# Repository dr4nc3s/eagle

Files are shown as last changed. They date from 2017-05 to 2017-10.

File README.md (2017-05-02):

# eagle #

My own Eagle components library as well as any PCB projects/designs I choose to work on. 

## Current Project - SAML21J breakout ##

Breakout board for using the SAML21J (yep, 64-pin). Currently putting together a list of features I want on the board. Don't want to make this too expensive, but I want enough features for me to utilize the various functions of the SAML21.

<h4>Features to Include</h4>
1. Power Supply : rails for 3.3V, 5V
2. microUSB port : for power input and programming
3. 10-pin JTAG header : for programming
4. External VREF circuitry : was told that internal VREF has a fair percentage error, so will want this out
5. Peripheral IO breakouts : breakouts specifically for some of the additional functions of the pins (I2C, UART, SPI, etc)
6. Status LEDs
7. USB-UART bridge (?) : unsure if I want this

## Future Projects ##

1. ESP32 breakout board (utilize WROOM module)
2. PIC breakout board - unsure whether I want PIC18, PIC24, or PIC32 architecture
3.

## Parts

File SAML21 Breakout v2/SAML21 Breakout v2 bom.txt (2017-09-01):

Partlist exported from C:/Users/Mobile Me/Documents/GitHub/eagle/SAML21 Breakout v1/SAML21 Breakout.sch at 6/23/2017 11:00 AM

Qty Value            Device           Package         Parts                    Description                               
1                    INDUCTOR0603     IND-0603        L1                                                                 ===
1                    JACK-PLUG0       SPC4077         J2                       DC POWER JACK                             ===
1                    SKHMQME010       SKHMQME010      S1                       ALPS Tactile Switch                       ===
6   100nF            CAP0603          CAP-0603        C1, C3, C4, C5, C16, C17 Multilayer Ceramic Capacitor              ===
6   10k              RESISTOR0805     RES-0805        R1, R4, R7, R9, R10, R11                                           ===
5   10uF             CAP0603          CAP-0603        C6, C7, C8, C12, C13     Multilayer Ceramic Capacitor              ===
2   15pF             CAP0603          CAP-0603        C10, C11                 Multilayer Ceramic Capacitor              
3   1uF              CAP0603          CAP-0603        C2, C9, C14              Multilayer Ceramic Capacitor              ===
2   2N7002           2N7002           SOT-23-3        Q1, Q2                   Fairchild ON Semiconductor                ===
1   32.768MHz        LFXTAL054236-R   CFPX-217        Y2                       Crystal 32.768MHz                         ===
5   330              RESISTOR0805     RES-0805        R2, R3, R5, R6, R8                                                 ===
1   3V3              LED1206          LED-1206        D1                                                                 ===
1   4.7uF            CAP0603          CAP-0603        C15                      Multilayer Ceramic Capacitor              ===
1   AP7362-33SP-13   AP7362-33SP-13   SO-8EP          U5                       Diodes Inc.                               ===
1   AT-SAM-L21-JTQFP AT-SAM-L21-JTQFP TQFP-64         U1                       Atmel/Microchip SAML21 Series, 64-pin     ===
2   M02              M02              1X02            JP10, JP11                                                         
5   M02LONG          M02LONG          1X02-LONG       JP4, JP5, JP6, JP7, JP9                                            
3   M03              M03              1X03            U$1, USB_EN, VREF_EN                                               
3   M122ROWS         M122ROWS         2X06            JP2, JP3, JP8                                                      
1   M142ROWS         M142ROWS         2X07            JP1                                                                ===
1   M50-4910545      M50-4910545      M50-4910545     J1                       Harwin 10-pin Connector                   
1   MCP1501-CHY      MCP1501-CHY      SOT-23-6        U3                       High Precision Buffered Voltage Reference ===
1   MOLEX_USBMICRO   MOLEX_USBMICRO   MOLEX_47346-001 U$6                                                                ===
3   PWR              LED1206          LED-1206        D2, D3, D4                                                         
1   TXS-0102-Q1      TXS-0102-Q1      VSSOP-8         U4                       Texas Instruments                         ===
1   VS-10BQ030-M3    VS-10BQ030-M3    DO-214AA        D5                       Vishay Semiconductors

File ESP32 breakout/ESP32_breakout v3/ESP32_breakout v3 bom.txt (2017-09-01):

Partlist exported from C:/Users/Mobile Me/Documents/GitHub/eagle/ESP32 breakout/ESP32_breakout v2.2/ESP32_breakout v2.2.sch at 6/23/2017 11:27 AM

Qty Value              Device               Package            Parts                                  Description                                             
1                      JACK-PLUG0           SPC4077            J1                                     DC POWER JACK                 ===                          
5                      LED1206              LED-1206           D1, D3, D4, D5, D6                                                   ===                          
2                      PUSHBUTTONSKHMQME010 SKHMQME010         S1, S2                                 ALPS Tactile Switch           ===                          
5   0.1uF              CAP0603              CAP-0603           C2, C3, C4, C9, C18                    Multilayer Ceramic Capacitor  ===                          
3   10k                RESISTOR0805         RES-0805           R1, R2, R8                                                            ===                         
2   10uF               CAP-POLARCASEB-3528  B-3528             C5, C6                                                               ===                          
1   10uF               CAP0603              CAP-0603           C1                                     Multilayer Ceramic Capacitor  ===                          
1   12MHz              ABLS-12MHZ-B2-T      HC-49/US           Y1                                     Abracon 12MHz Crystal          ===                         
2   22pF               CAP0805              CAP-0805           C7, C8                                 Multilayer Ceramic Capacitor  ===                          
5   330                RESISTOR0805         RES-0805           R3, R4, R5, R6, R7                                                   ===                          
3   BSS84              BSS84                SOT-23-3           Q1, Q2, Q3                             Fairchild Semiconductor       ===                          
1   CH340G             CH340G               SOIC16             U$7                                                                  ===                          
1   ESP-WROOM-32       ESP-WROOM-32         ESP-WROOM-32       U1                                                                   ===                          
1   JUMPER_2-WAY       JUMPER_2-WAY         1X02               JP6                                                                                            
2   M02LONG            M02LONG              1X02-LONG          JP4, JP5                                                                                       
2   M102X05            M102X05              2X05               JP2, JP3                                                                                       
1   M122ROWS           M122ROWS             2X06               JP1                                                                                            
1   MOLEX_USBMICRO     MOLEX_USBMICRO       MOLEX_47346-001    U$4                                                                                            
1   NCP-1117223-3      NCP-1117223-3        SOT-223-3          U2                                     ON Semiconductor Low Dropout Positive Voltage Regulator 
1   SCHA4B0419         SCHA4B0419           MICROSD_SCHA4B0419 J3                                     ALPS MicroSD Connector                                  
1   SPDT               SPDT                 1X03               S3                                                                                             
8   TOUCHPAD-10MMX10MM TOUCHPAD-10MMX10MM   TOUCH-10MMX10MM    C10, C11, C12, C13, C14, C15, C16, C17                                                         
1   VS-10BQ030-M3      VS-10BQ030-M3        DO-214AA           D2                                     Vishay Semiconductors

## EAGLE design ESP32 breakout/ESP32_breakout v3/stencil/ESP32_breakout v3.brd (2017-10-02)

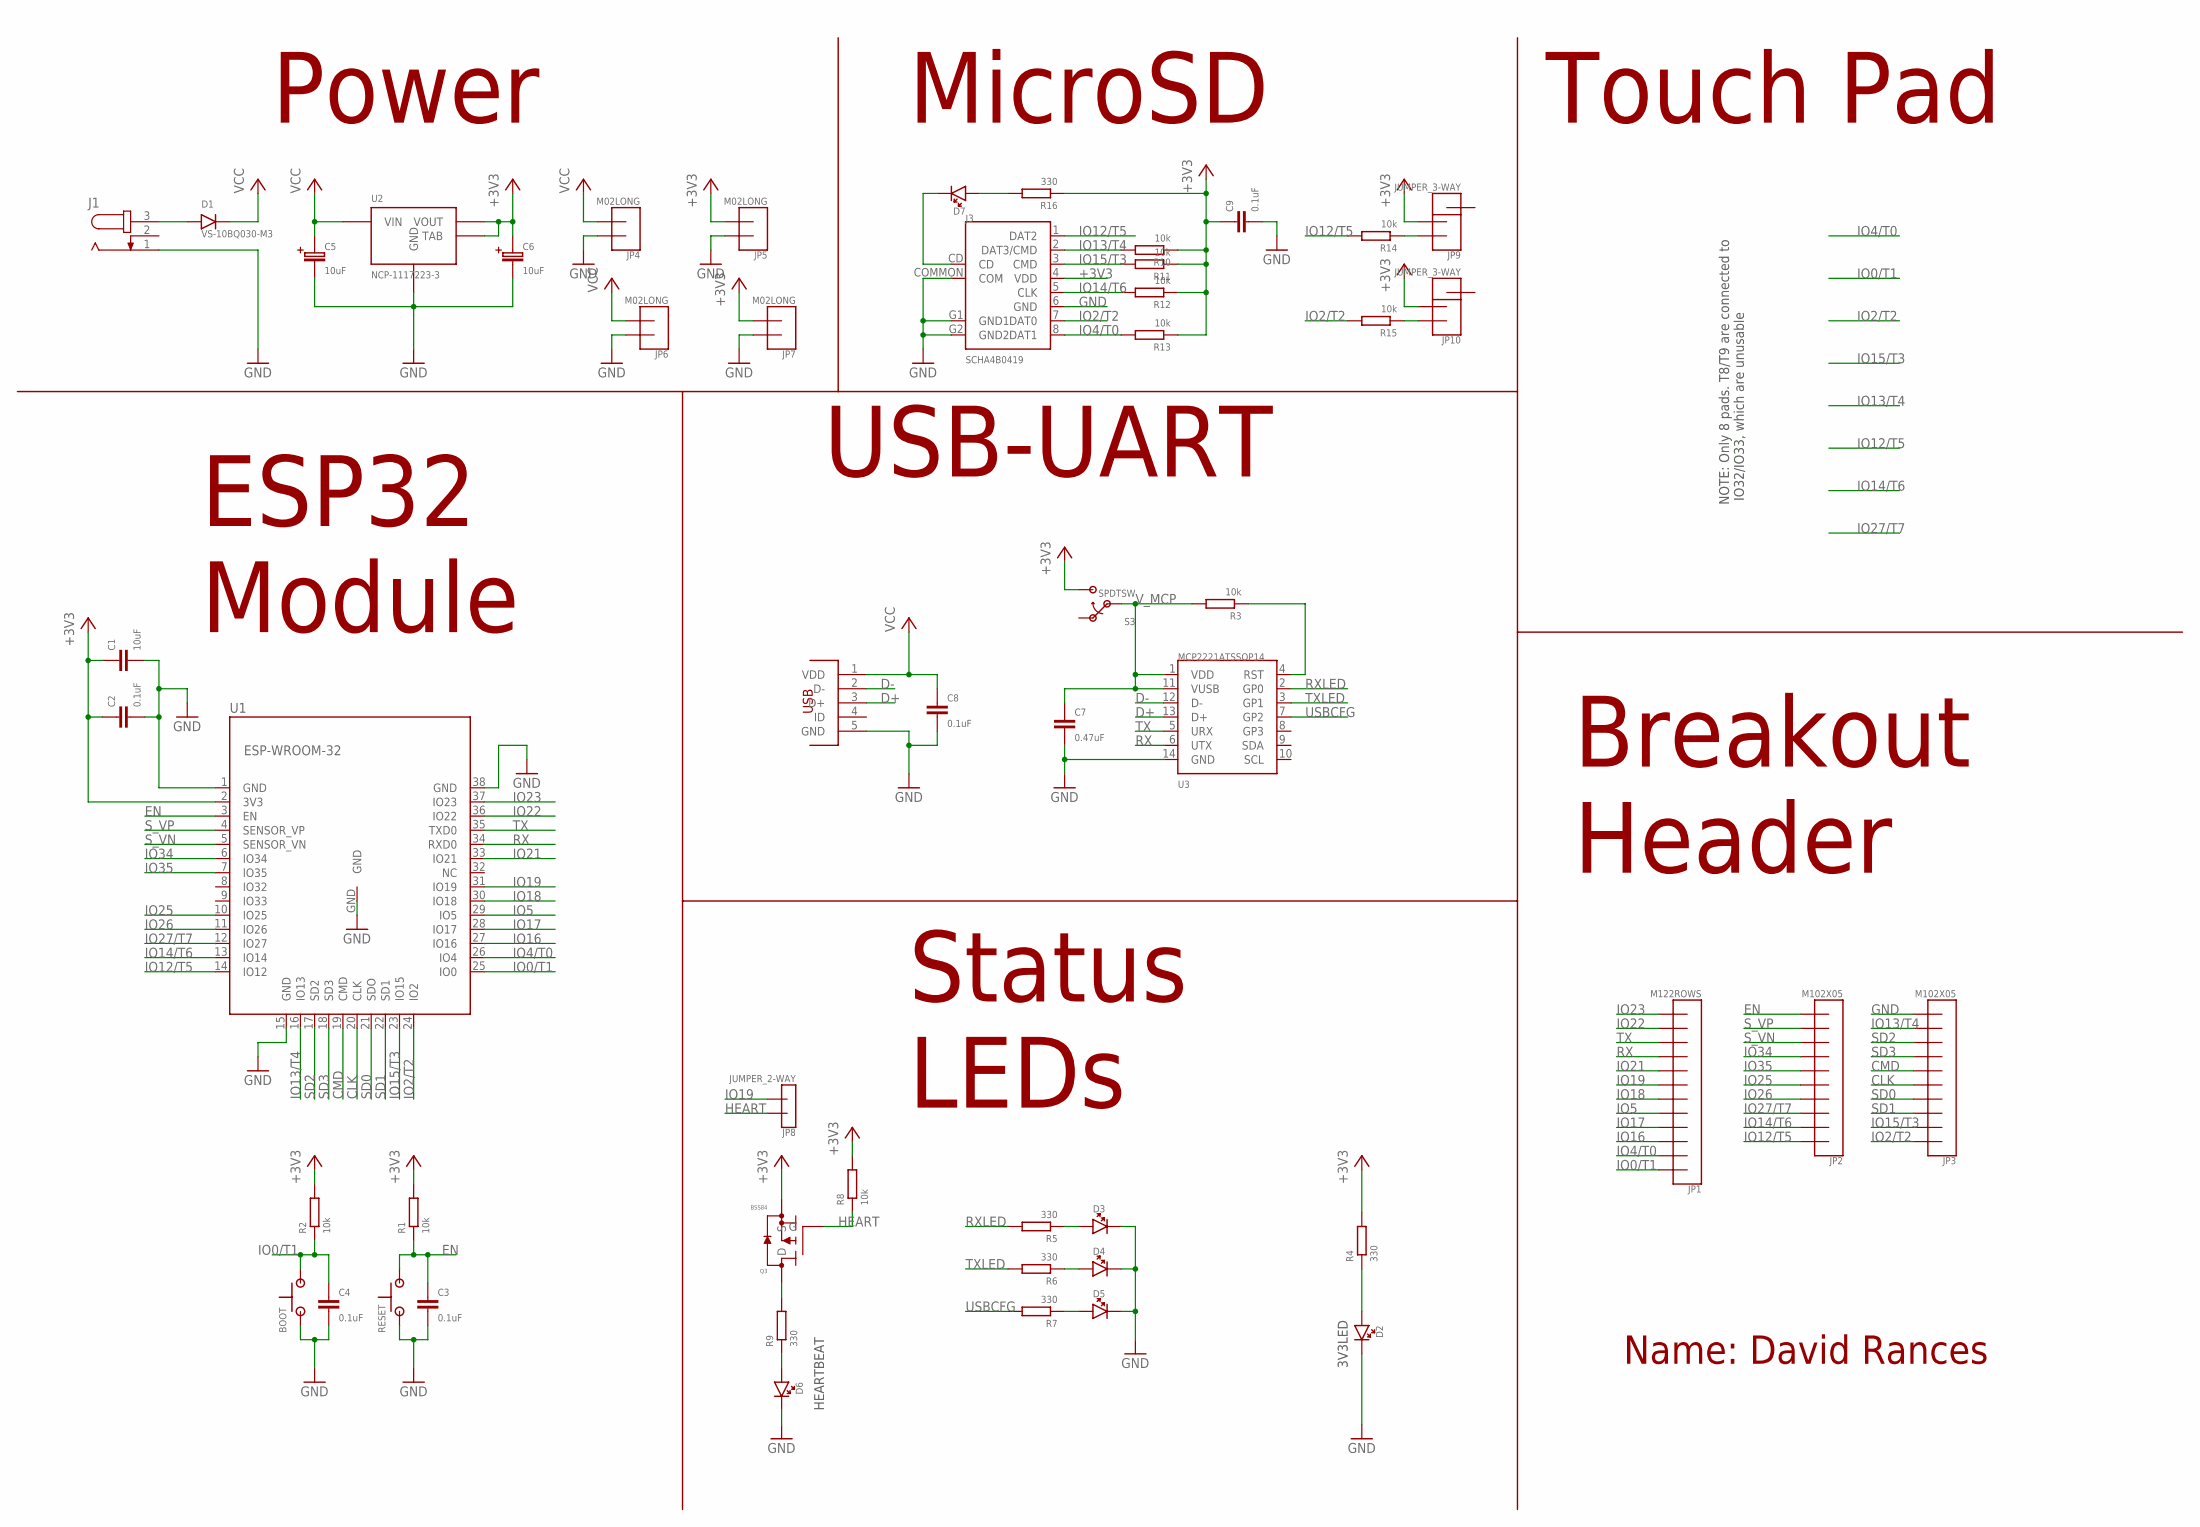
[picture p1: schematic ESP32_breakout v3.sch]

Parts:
BOOT: PUSHBUTTONSKHMQME010; SKHMQME010
C1: 10uF; CAP-0603
C2, C3, C4, C8, C9: 0.1uF; CAP-0603
C5, C6: 10uF; B-3528
C7: 0.47uF; CAP-0603
D1: VS-10BQ030-M3; DO-214AA
D2, D3, D4, D5, D6, D7: LED1206; LED-1206
J1: JACK-PLUG0; SPC4077
J3: SCHA4B0419; MICROSD_SCHA4B0419
JP1: M122ROWS; 2X06
JP2, JP3: M102X05; 2X05
JP4, JP5, JP6, JP7: M02LONG; 1X02-LONG
JP8: JUMPER_2-WAY; 1X02
JP9, JP10: JUMPER_3-WAY; 1X03
Q3: BSS84; SOT-23-3
R1, R2, R3, R8, R10, R11, R12, R13, R14, R15: 10k; RES-0603
R4, R5, R6, R7, R9, R16: 330; RES-0603
RESET: PUSHBUTTONSKHMQME010; SKHMQME010
S3: SPDTSW; SPDT_TH
U1: ESP-WROOM-32
U2: NCP-1117223-3; SOT-223-3
U3: MCP2221ATSSOP14; TSSOP-14
U$4: MOLEX_USBMICRO; MOLEX_47346-001

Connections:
+3V3: C1.1, C2.1, C6.P, C9.1, J3.4 (VDD), JP5.2, JP7.2, JP9.2, JP10.2, Q3.S, R1.2, R2.2, R4.2, R8.2, R10.1, R11.1, R12.1, R13.1, R16.1, S3.3 (2), U1.2 (3V3), U2.2 (VOUT), U2.PAD (TAB)
CLK: JP3.5, U1.20 (CLK)
CMD: JP3.6, U1.19 (CMD)
D+: U3.13 (D+), U$4.3 (D+)
D-: U3.12 (D-), U$4.2 (D-)
EN: C3.1, JP2.10, R1.1, RESET.3 (2), RESET.4 (2), U1.3 (EN)
GND: BOOT.1, BOOT.2 (1), C1.2, C2.2, C3.2, C4.2, C5.N, C6.N, C7.2, C8.2, C9.2, D2.C, D3.C, D4.C, D5.C, D6.C, J1.1, J3.6 (GND), J3.COMMON (COM), J3.G1 (GND1), J3.G2 (GND2), JP3.10, JP4.1, JP5.1, JP6.1, JP7.1, RESET.1, RESET.2 (1), U1.1 (GND), U1.15 (GND), U1.38 (GND), U1.GND, U2.1 (GND), U3.14 (GND), U$4.5 (GND)
HEART: JP8.1, Q3.G, R8.1
IO0/T1: BOOT.3 (2), BOOT.4 (2), C4.1, JP1.1, R2.1, U1.25 (IO0)
IO2/T2: J3.7 (DAT0), JP3.1, R15.2, U1.24 (IO2)
IO4/T0: J3.8 (DAT1), JP1.2, R13.2, U1.26 (IO4)
IO5: JP1.5, U1.29 (IO5)
IO12/T5: J3.1 (DAT2), JP2.1, R14.2, U1.14 (IO12)
IO13/T4: J3.2 (DAT3/CMD), JP3.9, R10.2, U1.16 (IO13)
IO14/T6: J3.5 (CLK), JP2.2, R12.2, U1.13 (IO14)
IO15/T3: J3.3 (CMD), JP3.2, R11.2, U1.23 (IO15)
IO16: JP1.3, U1.27 (IO16)
IO17: JP1.4, U1.28 (IO17)
IO18: JP1.6, U1.30 (IO18)
IO19: JP1.7, JP8.2, U1.31 (IO19)
IO21: JP1.8, U1.33 (IO21)
IO22: JP1.11, U1.36 (IO22)
IO23: JP1.12, U1.37 (IO23)
IO25: JP2.5, U1.10 (IO25)
IO26: JP2.4, U1.11 (IO26)
IO27/T7: JP2.3, U1.12 (IO27)
IO34: JP2.7, U1.6 (IO34)
IO35: JP2.6, U1.7 (IO35)
unnamed: D1.A, J1.3
unnamed: R3.1, U3.4 (RST)
unnamed: D5.A, R7.1
unnamed: D2.A, R4.1
unnamed: JP9.1, R14.1
unnamed: JP10.1, R15.1
unnamed: D3.A, R5.1
unnamed: D6.A, R9.1
unnamed: Q3.D, R9.2
unnamed: D4.A, R6.1
unnamed: D7.C, J3.CD
unnamed: D7.A, R16.2
RX: JP1.9, U1.34 (RXD0), U3.6 (UTX)
RXLED: R5.2, U3.2 (GP0)
SD0: JP3.4, U1.21 (SDO)
SD1: JP3.3, U1.22 (SD1)
SD2: JP3.8, U1.17 (SD2)
SD3: JP3.7, U1.18 (SD3)
S_VN: JP2.8, U1.5 (SENSOR_VN)
S_VP: JP2.9, U1.4 (SENSOR_VP)
TX: JP1.10, U1.35 (TXD0), U3.5 (URX)
TXLED: R6.2, U3.3 (GP1)
USBCFG: R7.2, U3.7 (GP2)
VCC: C5.P, C8.1, D1.C, JP4.2, JP6.2, U2.3 (VIN), U$4.1 (VDD)
V_MCP: C7.1, R3.2, S3.2 (OUT), U3.1 (VDD), U3.11 (VUSB)

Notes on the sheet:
NOTE: Only 8 pads. T8/T9 are connected to IO32/IO33, which are unusable
3V3LED
HEARTBEAT
Power
MicroSD
Touch Pad
ESP32 Module
Status LEDs
Breakout Header
USB-UART
Name: David Rances

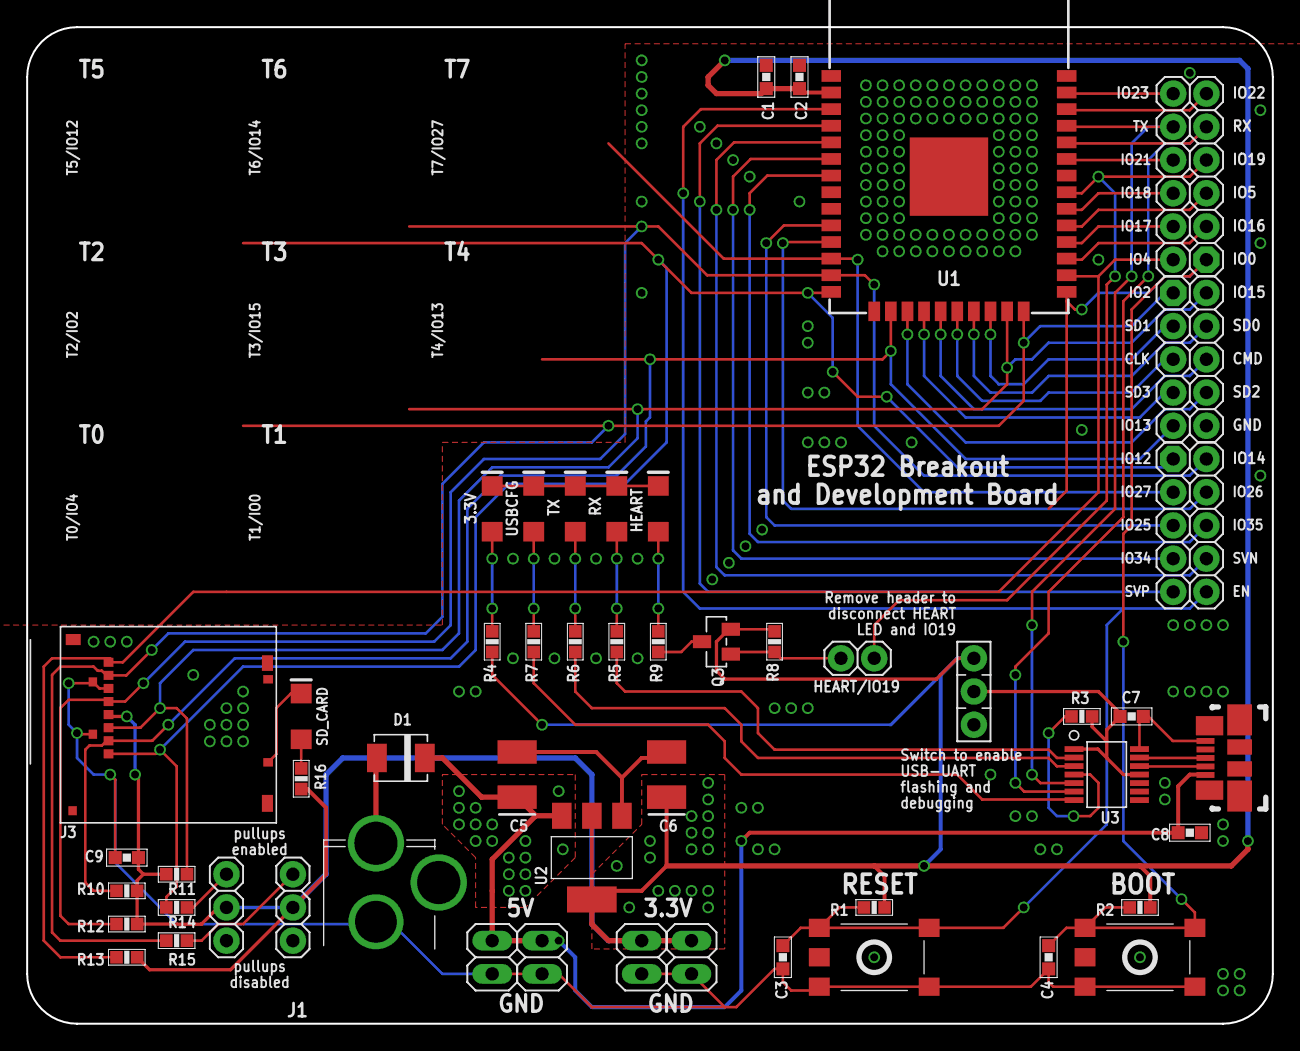
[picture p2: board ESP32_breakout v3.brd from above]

Board: 2 copper layers, 95.2 x 76.2 mm, 52 parts (0 on the bottom side), 53 nets.

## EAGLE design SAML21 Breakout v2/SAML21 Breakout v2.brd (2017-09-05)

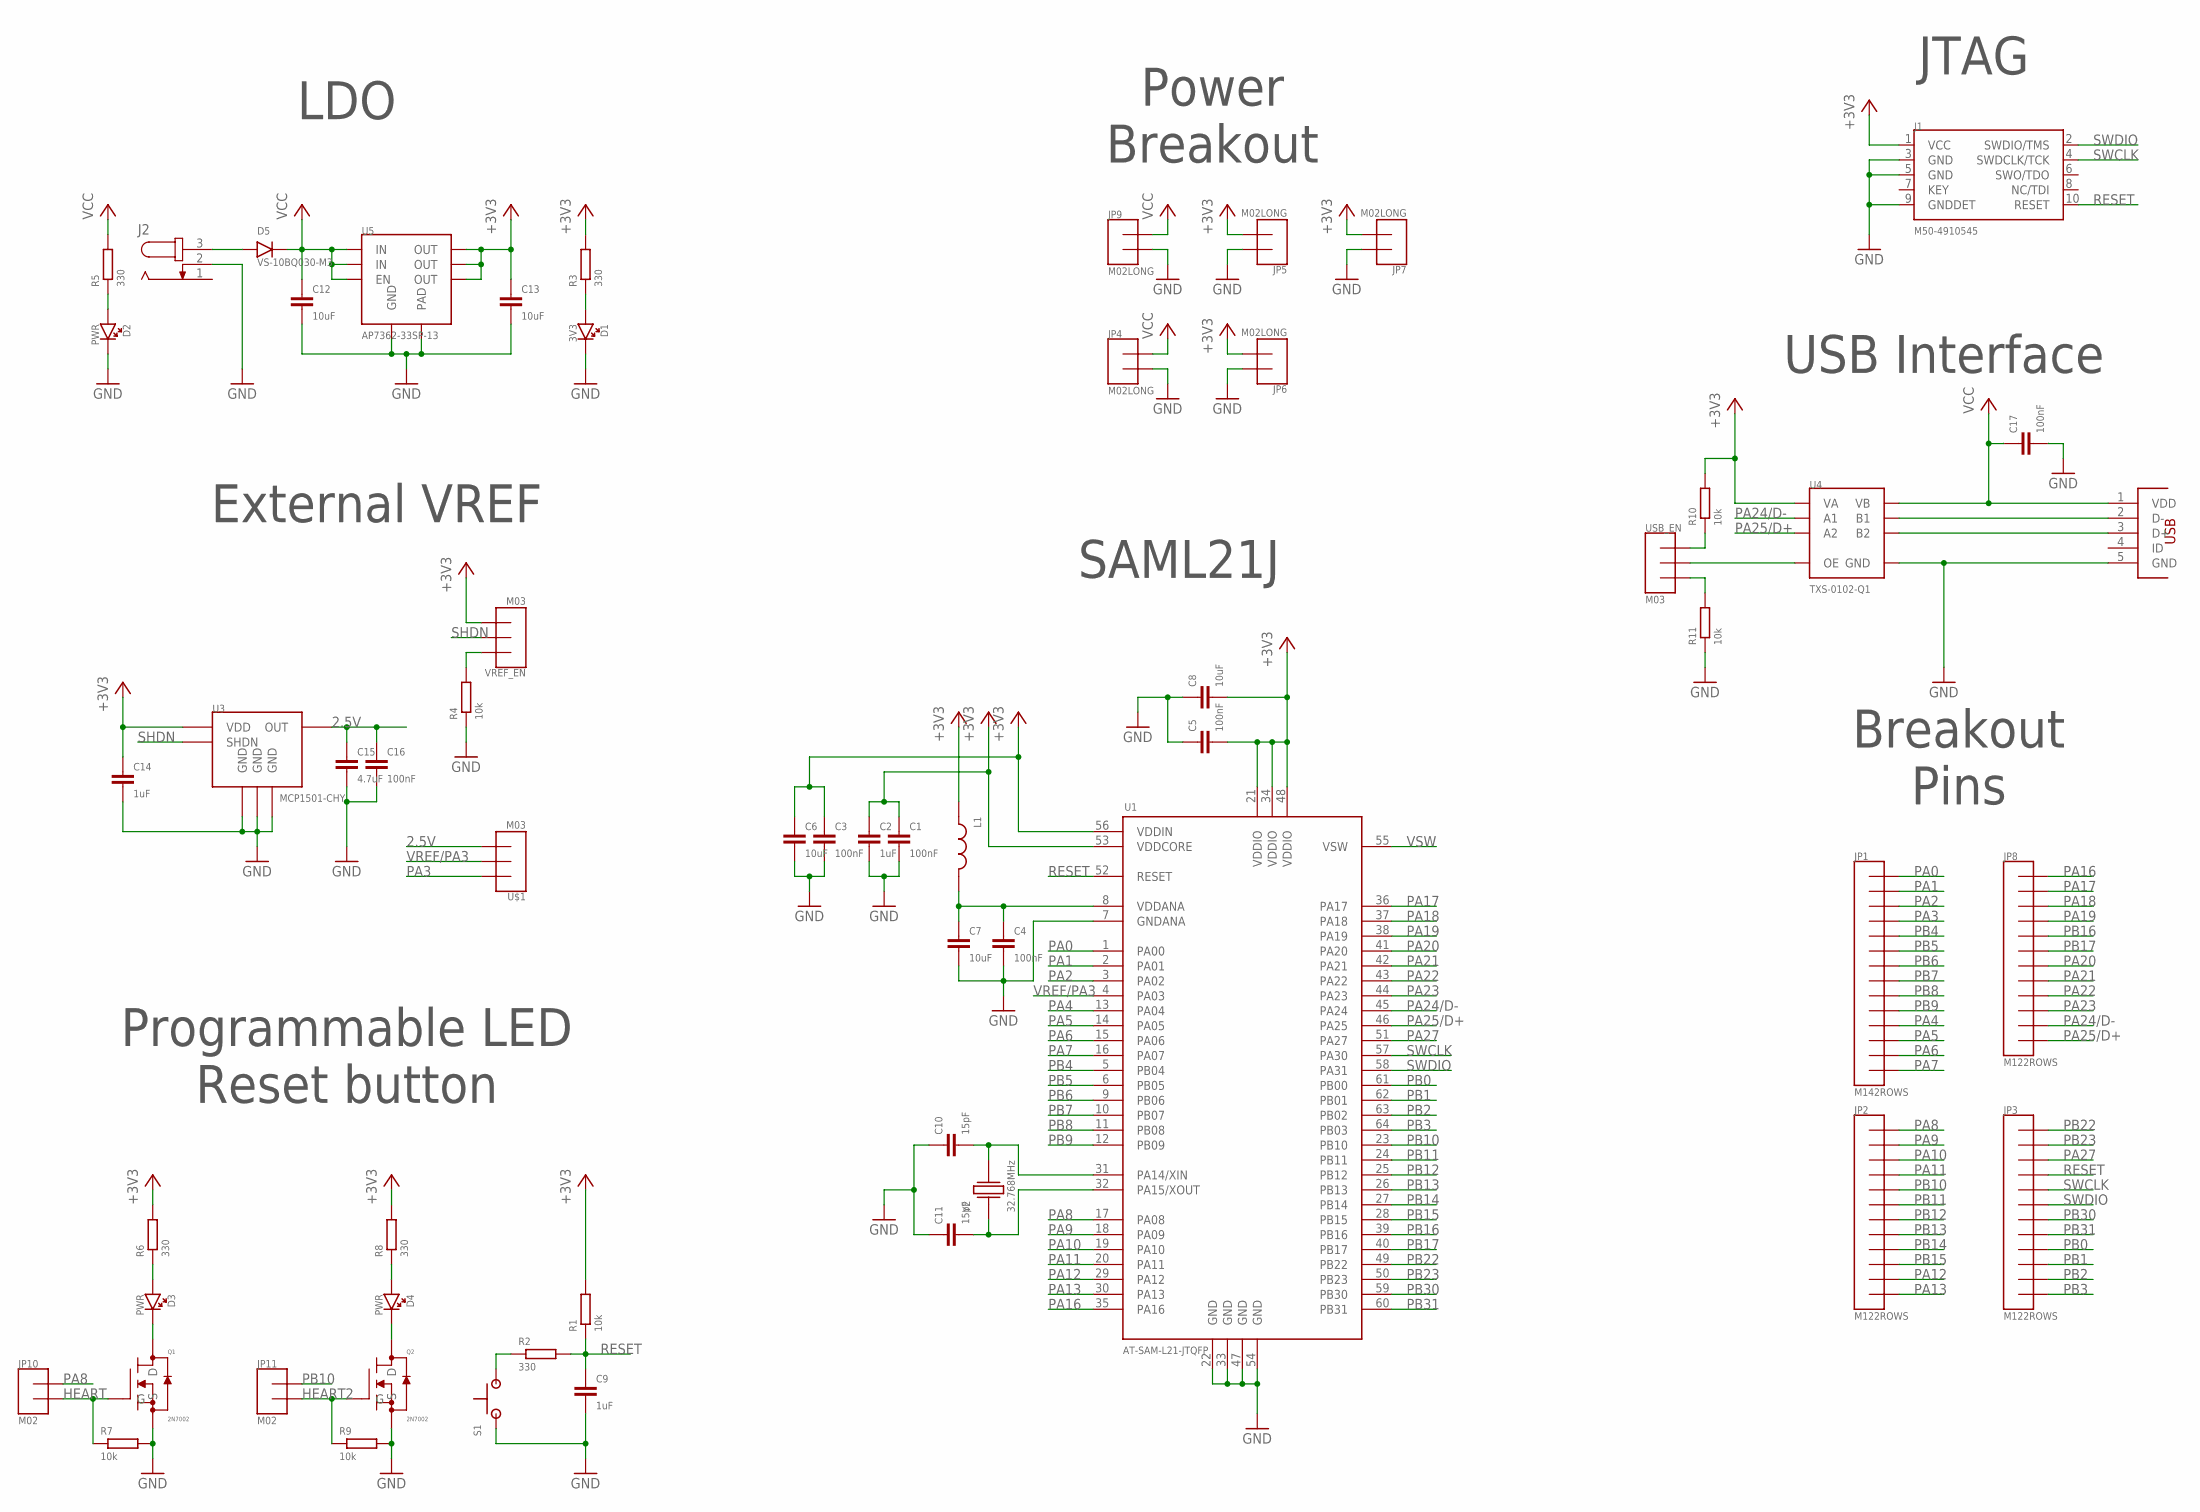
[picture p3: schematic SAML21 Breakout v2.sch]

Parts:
C1, C3, C4, C5, C16, C17: 100nF; CAP-0603
C2, C9, C14: 1uF; CAP-0603
C6, C7, C8, C12, C13: 10uF; CAP-0603
C10, C11: 15pF; CAP-0603
C15: 4.7uF; CAP-0805
D1: 3V3; LED-1206
D2, D3, D4: PWR; LED-1206
D5: VS-10BQ030-M3; DO-214AA
J1: M50-4910545
J2: JACK-PLUG0; SPC4077
JP1: M142ROWS; 2X07
JP2, JP3, JP8: M122ROWS; 2X06
JP4, JP5, JP6, JP7, JP9: M02LONG; 1X02-LONG
JP10, JP11: M02; 1X02
L1: INDUCTOR0603; IND-0603
Q1, Q2: 2N7002; SOT-23-3
R1, R4, R7, R9, R10, R11: 10k; RES-0805
R2, R3, R5, R6, R8: 330; RES-0805
S1: SKHMQME010
U1: AT-SAM-L21-JTQFP; TQFP-64
U3: MCP1501-CHY; SOT-23-6
U4: TXS-0102-Q1; VSSOP-8
U5: AP7362-33SP-13; SO-8EP
U$1: M03; 1X03
U$6: MOLEX_USBMICRO; MOLEX_47346-001
USB_EN: M03; 1X03
VREF_EN: M03; 1X03
Y2: 32.768MHz; CFPX-217

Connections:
2.5V: C15.1, C16.1, U3.1 (OUT), U$1.3
+3V3: C1.1, C2.1, C3.1, C5.2, C6.1, C8.2, C13.1, C14.1, J1.1 (VCC), JP5.2, JP6.2, JP7.2, L1.1, R1.2, R3.2, R6.2, R8.2, R10.2, U1.21 (VDDIO), U1.34 (VDDIO), U1.48 (VDDIO), U1.53 (VDDCORE), U1.56 (VDDIN), U3.6 (VDD), U4.3 (VA), U5.5 (OUT), U5.6 (OUT), U5.7 (OUT), VREF_EN.3
GND: C1.2, C2.2, C3.2, C4.2, C5.1, C6.2, C7.2, C8.1, C9.2, C10.1, C11.1, C12.2, C13.2, C14.2, C15.2, C16.2, C17.2, D1.C, D2.C, J1.3 (GND), J1.5 (GND), J1.9 (GNDDET), J2.2, JP4.2, JP5.1, JP6.1, JP7.1, JP9.2, Q1.S, Q2.S, R4.1, R7.2, R9.2, R11.1, S1.1, U1.7 (GNDANA), U1.22 (GND), U1.33 (GND), U1.47 (GND), U1.54 (GND), U3.2 (GND), U3.3 (GND), U3.5 (GND), U4.2 (GND), U5.1 (GND), U5.PAD, U$6.5 (GND)
HEART: JP10.2, Q1.G, R7.1
HEART2: JP11.2, Q2.G, R9.1
unnamed: R2.1, S1.3 (2)
unnamed: D1.A, R3.1
unnamed: C4.1, C7.1, L1.2, U1.8 (VDDANA)
unnamed: C10.2, U1.31 (PA14/XIN), Y2.2
unnamed: C11.2, U1.32 (PA15/XOUT), Y2.1
unnamed: D2.A, R5.1
unnamed: R4.2, VREF_EN.1
unnamed: D3.A, R6.1
unnamed: D3.C, Q1.D
unnamed: D4.A, R8.1
unnamed: D4.C, Q2.D
unnamed: D5.A, J2.3
unnamed: R10.1, USB_EN.1
unnamed: U4.8 (B1), U$6.2 (D-)
unnamed: U4.1 (B2), U$6.3 (D+)
unnamed: R11.2, USB_EN.3
unnamed: U4.6 (OE), USB_EN.2
PA0: JP1.1, U1.1 (PA00)
PA1: JP1.2, U1.2 (PA01)
PA2: JP1.3, U1.3 (PA02)
PA3: JP1.4, U$1.1
PA4: JP1.11, U1.13 (PA04)
PA5: JP1.12, U1.14 (PA05)
PA6: JP1.13, U1.15 (PA06)
PA7: JP1.14, U1.16 (PA07)
PA8: JP2.1, JP10.1, U1.17 (PA08)
PA9: JP2.2, U1.18 (PA09)
PA10: JP2.3, U1.19 (PA10)
PA11: JP2.4, U1.20 (PA11)
PA12: JP2.11, U1.29 (PA12)
PA13: JP2.12, U1.30 (PA13)
PA16: JP8.1, U1.35 (PA16)
PA17: JP8.2, U1.36 (PA17)
PA18: JP8.3, U1.37 (PA18)
PA19: JP8.4, U1.38 (PA19)
PA20: JP8.7, U1.41 (PA20)
PA21: JP8.8, U1.42 (PA21)
PA22: JP8.9, U1.43 (PA22)
PA23: JP8.10, U1.44 (PA23)
PA24/D-: JP8.11, U1.45 (PA24), U4.5 (A1)
PA25/D+: JP8.12, U1.46 (PA25), U4.4 (A2)
PA27: JP3.3, U1.51 (PA27)
PB0: JP3.9, U1.61 (PB00)
PB1: JP3.10, U1.62 (PB01)
PB2: JP3.11, U1.63 (PB02)
PB3: JP3.12, U1.64 (PB03)
PB4: JP1.5, U1.5 (PB04)
PB5: JP1.6, U1.6 (PB05)
PB6: JP1.7, U1.9 (PB06)
PB7: JP1.8, U1.10 (PB07)
PB8: JP1.9, U1.11 (PB08)
PB9: JP1.10, U1.12 (PB09)
PB10: JP2.5, JP11.1, U1.23 (PB10)
PB11: JP2.6, U1.24 (PB11)
PB12: JP2.7, U1.25 (PB12)
PB13: JP2.8, U1.26 (PB13)
PB14: JP2.9, U1.27 (PB14)
PB15: JP2.10, U1.28 (PB15)
PB16: JP8.5, U1.39 (PB16)
PB17: JP8.6, U1.40 (PB17)
PB22: JP3.1, U1.49 (PB22)
PB23: JP3.2, U1.50 (PB23)
PB30: JP3.7, U1.59 (PB30)
PB31: JP3.8, U1.60 (PB31)
RESET: C9.1, J1.10 (RESET), JP3.4, R1.1, R2.2, U1.52 (RESET)
SHDN: U3.4 (SHDN), VREF_EN.2
SWCLK: J1.4 (SWDCLK/TCK), JP3.5, U1.57 (PA30)
SWDIO: J1.2 (SWDIO/TMS), JP3.6, U1.58 (PA31)
VCC: C12.1, C17.1, D5.C, JP4.1, JP9.1, R5.2, U4.7 (VB), U5.2 (EN), U5.3 (IN), U5.4 (IN), U$6.1 (VDD)
VREF/PA3: U1.4 (PA03), U$1.2
VSW: U1.55 (VSW)

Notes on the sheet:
SAML21J
Breakout Pins
JTAG
Power Breakout
LDO
External VREF
Programmable LED Reset button
USB Interface

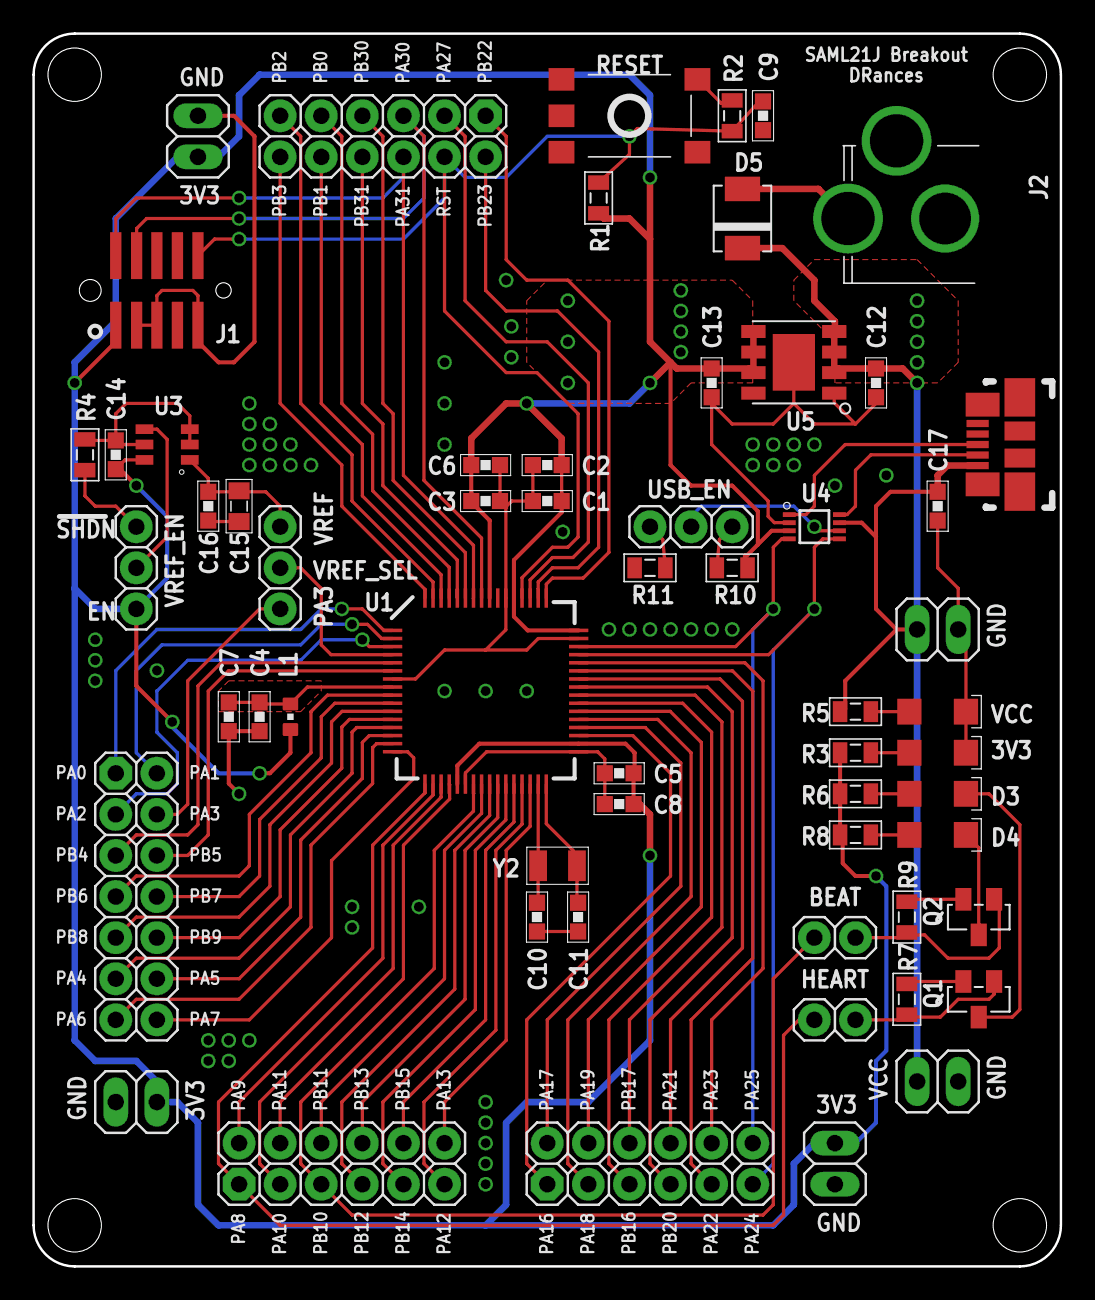
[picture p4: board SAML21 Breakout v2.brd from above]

Board: 2 copper layers, 63.5 x 76.2 mm, 63 parts (0 on the bottom side), 75 nets.

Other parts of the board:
U$2, U$3, U$4, U$5: STAND-OFF-HOLE

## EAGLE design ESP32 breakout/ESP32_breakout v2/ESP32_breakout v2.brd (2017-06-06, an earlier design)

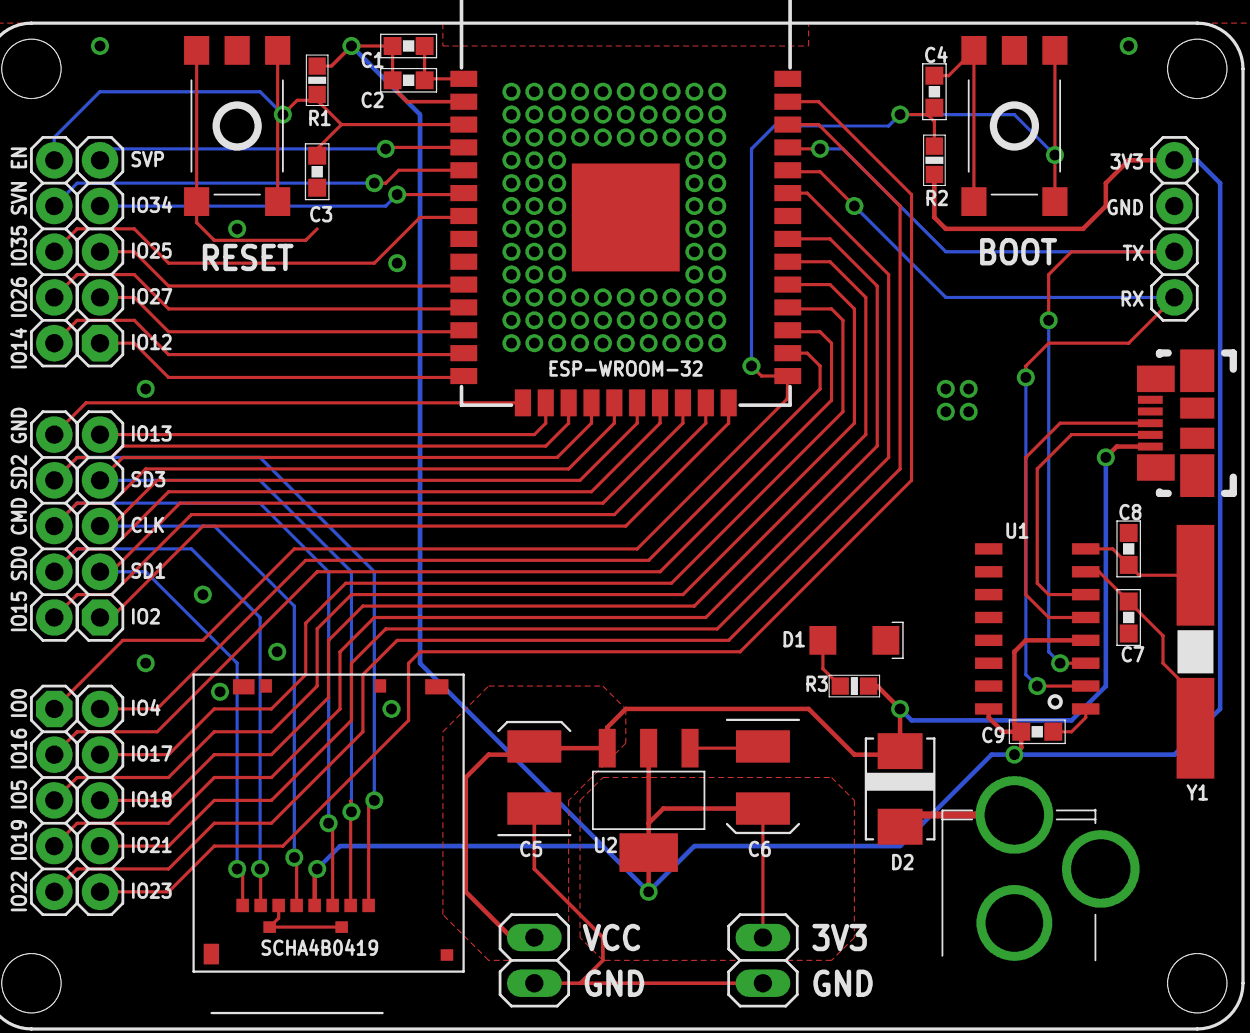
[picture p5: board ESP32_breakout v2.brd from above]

Board: 2 copper layers, 33 parts (0 on the bottom side), 40 nets.

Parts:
C1: 10uF; CAP-0603
C2, C3, C4, C9: 0.1uF; CAP-0603
C5, C6: 10uF; B-3528
C7, C8: 22pF; CAP-0603
D1: LED-1206
D2: DIODE-10BQ015PBF; 10BQ015PB
J1: SPC4077
R1, R2: 10k; RES-0603
R3: 330; RES-0603
S1, S2: SKHMQME010
U1: ESP-WROOM-32
U2: NCP-1117; SOT-223-4
U$1, U$9: M02LONG; 1X02-LONG
U$2, U$5, U$17: M102X05; 2X05
U$3, U$6, U$14, U$15: STAND-OFF-HOLE
U$4: MOLEX_USBMICRO; MOLEX_47346-001
U$7: CH340G; SOIC16
U$8: SCHA4B0419; MICROSD_SCHA4B0419
U$10: M04; 1X04
Y1: 12MHz; HC-49/US

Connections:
+3V3: C1.1, C2.1, C6.P, C9.2, R1.2, R2.2, U1.2, U2.2, U2.PAD, U$7.4, U$7.16, U$8.4, U$9.2, U$10.4
CLK: U1.20, U$8.5, U$17.5
CMD: U1.19, U$8.3, U$17.6
EN: C3.1, R1.1, S1.3, S1.4, U1.3, U$5.10
GND: C1.2, C2.2, C3.2, C4.2, C5.N, C6.N, C7.2, C8.2, C9.1, D1.C, J1.1, S1.1, S1.2, S2.1, S2.2, U1.1, U1.15, U1.38, U1.GND, U2.1, U$1.1, U$4.5, U$7.1, U$8.6, U$8.G1, U$8.G2, U$9.1, U$10.3, U$17.10
IO0: C4.1, R2.1, S2.3, S2.4, U1.25, U$2.1
IO2: U1.24, U$17.1
IO4: U1.26, U$2.2
IO5: U1.29, U$2.5
IO12: U1.14, U$5.1
IO13: U1.16, U$17.9
IO14: U1.13, U$5.2
IO15: U1.23, U$17.2
IO16: U1.27, U$2.3
IO17: U1.28, U$2.4
IO18: U1.30, U$2.6
IO19: U1.31, U$2.7
IO21: U1.33, U$2.8
IO22: U1.36, U$2.9
IO23: U1.37, U$2.10
IO25: U1.10, U$5.5
IO26: U1.11, U$5.4
IO27: U1.12, U$5.3
IO34: U1.6, U$5.7
IO35: U1.7, U$5.6
unnamed: D1.A, R3.1
unnamed: D2.A, J1.3
unnamed: C7.1, U$7.7, Y1.P$1
unnamed: C8.1, U$7.8, Y1.P$2
unnamed: U$4.3, U$7.5
unnamed: U$4.2, U$7.6
RX: U1.34, U$7.2, U$10.1
SD0: U1.21, U$8.7, U$17.4
SD1: U1.22, U$8.8, U$17.3
SD2: U1.17, U$8.1, U$17.8
SD3: U1.18, U$8.2, U$17.7
S_VN: U1.5, U$5.8
S_VP: U1.4, U$5.9
TX: U1.35, U$7.3, U$10.2
VCC: C5.P, D2.C, R3.2, U2.3, U$1.2, U$4.1

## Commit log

2017-04-17 Added verification project
    [verify.brd, verify.sch]
2017-04-18 Edited packages
    [verify.brd, verify.sch]
2017-04-18 Added new devices
2017-04-18 New project
    [SAMD21-breakout v1.sch]
2017-04-24 New parts
    [SAMD21-breakout v1.sch, SAML21 Breakout.sch]
2017-04-25 Added crystal
    [SAML21 Breakout.sch]
2017-04-28 More parts
    [SAML21 Breakout.brd, SAML21 Breakout.sch]
2017-04-28 Some changes
    [SAML21 Breakout.brd, SAML21 Breakout.sch]
2017-05-03 ESP32 breakout started
    [ESP32_breakout v1.sch]
2017-05-09 Write pins
    [ESP32_breakout v1.sch]
2017-05-09 Header breakouts added
    [ESP32_breakout v1.brd, ESP32_breakout v1.sch]
2017-05-09 Rough component placement
    [ESP32_breakout v1.sch]
2017-05-10 Added USB ccomponents
    [ESP32_breakout v1.brd, ESP32_breakout v1.sch]
2017-05-10 Added ALPS new microsd connector
2017-05-13 PCB layout
    [ESP32_breakout v1.brd]
2017-05-13 ESP32 v1 done
    [ESP32_breakout v1.brd]
2017-05-16 Finish layout
    [ESP32_breakout v1.brd, ESP32_breakout v1.sch]
2017-05-16 Generate output files
    [ESP32_breakout v1.GBL, ESP32_breakout v1.GBO, ESP32_breakout v1.GBP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]
2017-05-20 Added ams CCS811 Indoor Gas Sensor package
2017-06-05 Swtiched microUSB breakout
    [ESP32 Rev1.sch, ESP32_breakout v2.brd, ESP32_breakout v2.sch]
2017-06-05 Made rounded board. Modified component libraries
    [ESP32_breakout v2.brd]
2017-06-05 Resized PCB v2
    [ESP32_breakout v2.brd, ESP32_breakout v2.sch]
2017-06-05 Finished major traces
    [ESP32_breakout v2.brd, ESP32_breakout v2.sch]
2017-06-05 Version 2, pre-check
    [ESP32_breakout v2.brd, ESP32_breakout v2.sch]
2017-06-05 Added labels
    [ESP32_breakout v2.brd]
2017-06-06 More vias
    [ESP32_breakout v2.brd]
2017-06-06 Added external vref
    [SAML21 Breakout.brd]
2017-06-06 PCB with touchpad
    [ESP32_breakout v2.1.brd, ESP32_breakout v2.1.sch]
2017-06-06 PCB touchpad
2017-06-07 Added more status LEDs
    [ESP32_breakout v2.1.brd, ESP32_breakout v2.1.sch]
2017-06-08 Added USB bypass cap and extra status LED
    [ESP32_breakout v2.1.brd, ESP32_breakout v2.1.sch]
2017-06-09 Modified labels
    [ESP32_breakout v2.1.brd, ESP32_breakout v2.1.sch]
2017-06-12 Add 2nd status LED
2017-06-13 DRU check
    [ESP32_breakout v2.1.brd, ESP32_breakout v2.1.sch]
2017-06-14 gerber generated
    [ESP32_breakout v2.1.GBL, ESP32_breakout v2.1.GBO, ESP32_breakout v2.1.GBP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]
2017-06-15 Added switch for USB-UART
    [ESP32_breakout v2.2.GBL, ESP32_breakout v2.2.GBO, ESP32_breakout v2.2.GBP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]
2017-06-16 Board layout started
    [SAML21 Breakout.brd, SAML21 Breakout.sch]
2017-06-20 component layout
    [SAML21 Breakout.brd, SAML21 Breakout.sch]
2017-06-21 Added USB interface
    [SAML21 Breakout.brd, SAML21 Breakout.sch]
2017-06-23 Component size change
    [SAML21 Breakout.brd, SAML21 Breakout.sch]
2017-09-01 Fixing conflicts
    [ESP32_breakout v2.1.GBL, ESP32_breakout v2.1.GBO, ESP32_breakout v2.1.GBP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]
2017-09-01 Added SAML21 v2
    [SAML21 Breakout v2.brd, SAML21 Breakout v2.sch]
2017-09-01 Layout and 80% routing done
    [ESP32_breakout v3.brd, ESP32_breakout v3.sch]
2017-09-05 Generated gerber
    [SAML21 Breakout v2.GBL, SAML21 Breakout v2.GBO, SAML21 Breakout v2.GBP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]
2017-09-08 v3 routing
    [ESP32_breakout v3.brd, ESP32_breakout v3.sch]
2017-09-10 Finished tracing part 2
    [ESP32_breakout v3.brd]
2017-09-11 PCB made
    [ESP32_breakout v3.GBL, ESP32_breakout v3.GBO, ESP32_breakout v3.GBP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]
2017-09-14 Printout of Xbee
    [verify.brd, verify.sch]
2017-09-19 Added LED for microSD CD
    [ESP32_breakout v3.brd, ESP32_breakout v3.sch]
2017-09-19 Generate gerber files
    [ESP32_breakout v3.GTL, ESP32_breakout v3.GTO, ESP32_breakout v3.GTP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]
2017-09-21 Modified slide switch spdt
2017-10-02 Project file without touchpads
    Strictly for stencil generation
    [ESP32_breakout v3.brd, ESP32_breakout v3.sch]
